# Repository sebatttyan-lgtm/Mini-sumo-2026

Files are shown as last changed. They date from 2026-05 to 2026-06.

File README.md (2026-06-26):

# MARK 38(mini sumo)

## DESCRIPCIÓN
El proyecto es un robot mini sumo diseñado por nosotros, con un tamaño y peso correspondiente a las [reglas de la LNR (Liga Nacional de Robótica)](https://sistema.lnr-argentina.com.ar/reglamentos/Sumo). este tiene la capacidad de detectar al contrincante para ir y atacar al otro mini sumo con el que este compitiendo para dejarlo fuera del dojo.

## ADMINISTRADORES DEL PROYECTO
1. **Thiago Lopez.** Diseño 3D y montaje de componentes en placa.
2. **Enzo Zapata.** Diseño de PCB, esquemático y montaje de componentes en placa. 
3. **Sebastián Pérez.** Programación, diseño esquemático y PCB y montaje de componentes en placa. 

## OBJETIVO
Nuestra meta con este proyecto es poder participar en la [LNR(Liga Nacional de Robótica)](https://lnr-argentina.com.ar/) y quedar en un puesto alto a la hora de terminar la competencia.Además, queremos lograr también la programación de mini sumo RC para poder competir entre amigos. 

## ESPECIFICACIONES TÉCNICAS
#### Tamaño del mini sumo: 10cm x 10cm x 8cm
#### Alimentación de operación: 11.1v 450mAh
#### Material empleado en la carrocería: PLA
#### Tipos de sensores empleados: Infrarrojo
#### Fuerza de torque:30Nm (Newton metros)

## COMPONENTES
### - SENSORES DE OBSTÁCULOS
#### [VL53L0X](https://components101.com/sensors/vl53l0x-lidar-distance-sensor) *(x5)*
### - SENSORES DE PISO
#### [QRE1113](https://www.alldatasheet.es/datasheet-pdf/view/54347/FAIRCHILD/QRE1113.html) *(x2)*
### - MOTORES
#### [MICROMOTORES N30 500rpm](https://www.aslongdcmotor.com/photo/aslongdcmotor/document/26865/JGA12-N30.pdf) *(x2)*
### - MICROCONTROLADOR 
#### [ESP32 C3 super mini](www.google.com/search?q=esp32+c3+super+mini&oq=esp32+c3+super+mini&gs_lcrp=EgZjaHJvbWUyBggAEEUYOdIBCDg1NzBqMGo3qAIAsAIA&sourceid=chrome&ie=UTF-8) *(x1)* 
### - DRIVER DE MOTOR (puente H)
#### [TA6586](https://www.alldatasheet.com/datasheet-pdf/pdf/1761575/RZ-MIC/TA6586.html) *(x2)*
### - BATERIA
#### [Tattu 3S 450mAh 11.1V 75C XT30](https://www.hobbymotors.com.ar/store/index.php?route=product/product&product_id=1127) *(x1)*
> (estos componentes son a grandes rasgos y no se han colocado todos los componentes, en el archivo "lista de componentes se encontrarán todos los materiales utilizados durante la produccion").

## DISEÑO DE LA PLACA

<div align="center">
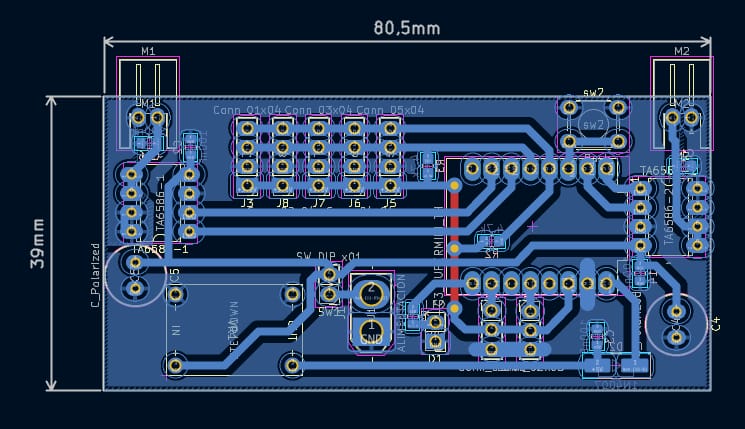
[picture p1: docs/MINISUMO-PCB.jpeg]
PCB Mini-sumo


## DISEÑO ESQUEMÁMITCO

<div align="center">
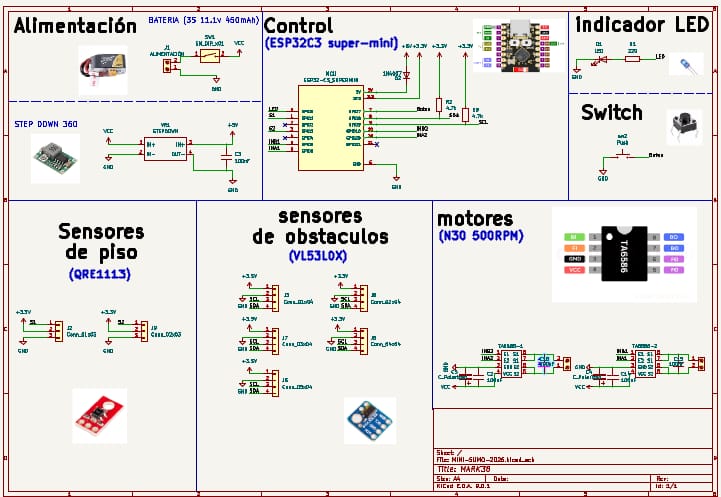
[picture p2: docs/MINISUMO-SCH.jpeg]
esquematico Mini-sumo


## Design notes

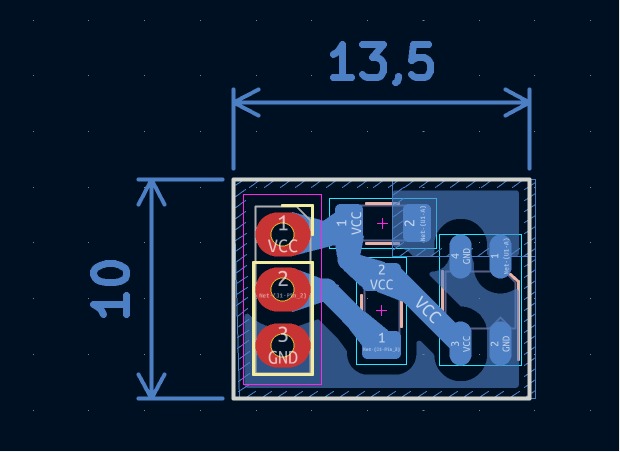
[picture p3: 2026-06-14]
docs/SENSORES-PCB.jpeg

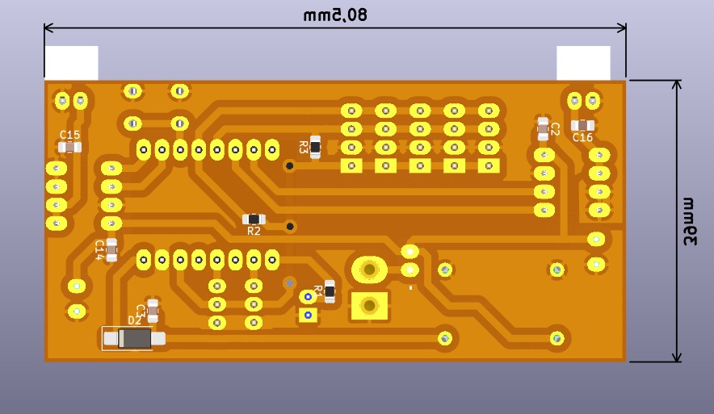
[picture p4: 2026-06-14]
docs/MINISUMO-3D-TRASERA.jpeg

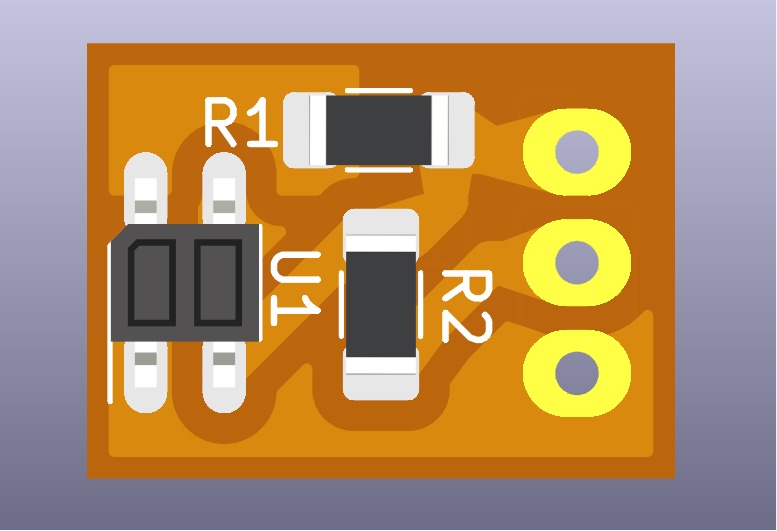
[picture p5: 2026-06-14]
docs/SENSORES-3D-TRASERA.jpeg

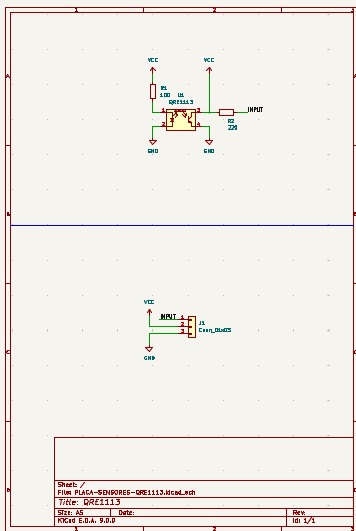
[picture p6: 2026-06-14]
docs/SENSORES-SCH.jpeg

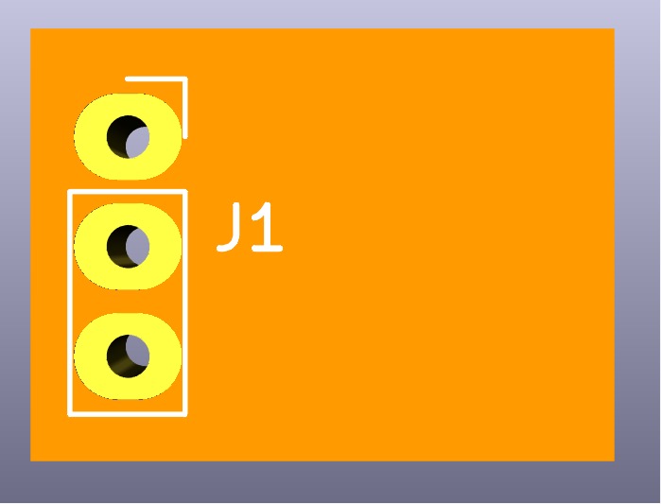
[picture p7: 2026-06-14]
docs/SENSORES-3D-FRONTAL.jpeg

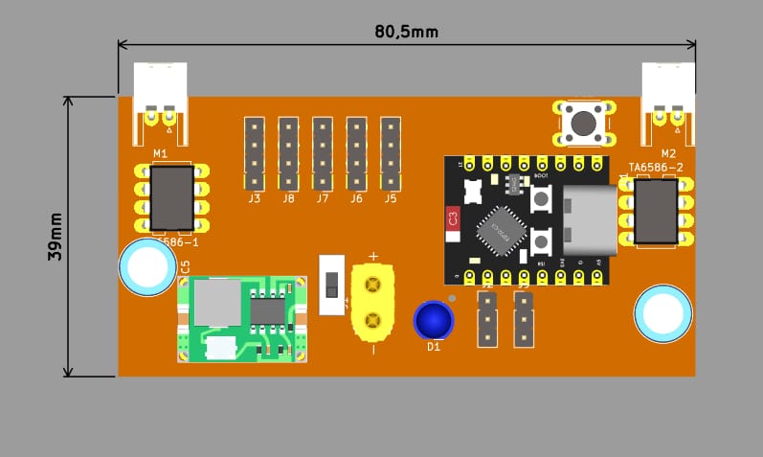
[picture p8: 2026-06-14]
docs/MINISUMO-3D-FRONTAL.jpeg

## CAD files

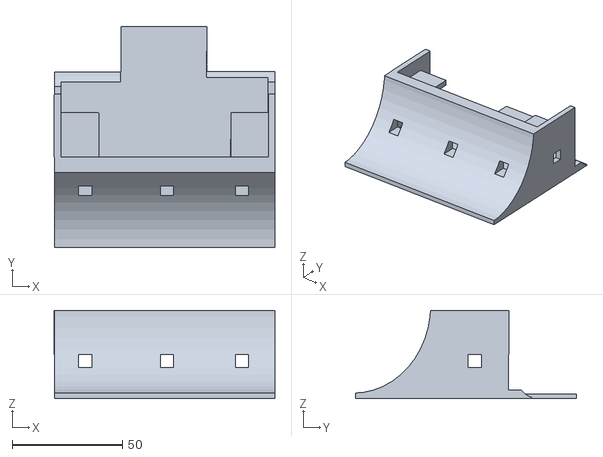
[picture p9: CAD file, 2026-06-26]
diseño 3D/MINI-SUMO.stl
100.2 x 100.0 x 40.0

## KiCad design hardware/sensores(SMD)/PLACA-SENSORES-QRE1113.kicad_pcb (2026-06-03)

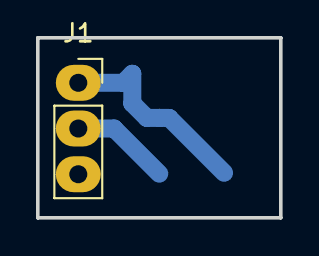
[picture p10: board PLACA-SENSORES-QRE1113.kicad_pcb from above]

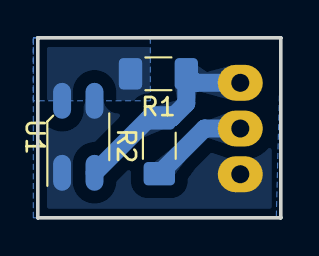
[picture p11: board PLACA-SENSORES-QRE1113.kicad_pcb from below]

Board: 2 copper layers, 13.5 x 10.0 mm, 4 parts (3 on the bottom side), 4 nets.

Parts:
J1: Conn_01x03; PinSocket_1x03_P2.54mm_Vertical
R1: 100; R_1206_3216Metric_Pad1.30x1.75mm_HandSolder
R2: 220; R_1206_3216Metric_Pad1.30x1.75mm_HandSolder
U1: QRE1113; OnSemi_CASE100AQ

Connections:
GND: J1.3, U1.2 (K), U1.4
unnamed: J1.2, R2.1
unnamed: R1.2, U1.1 (A)
VCC: J1.1, R1.1, R2.2, U1.3

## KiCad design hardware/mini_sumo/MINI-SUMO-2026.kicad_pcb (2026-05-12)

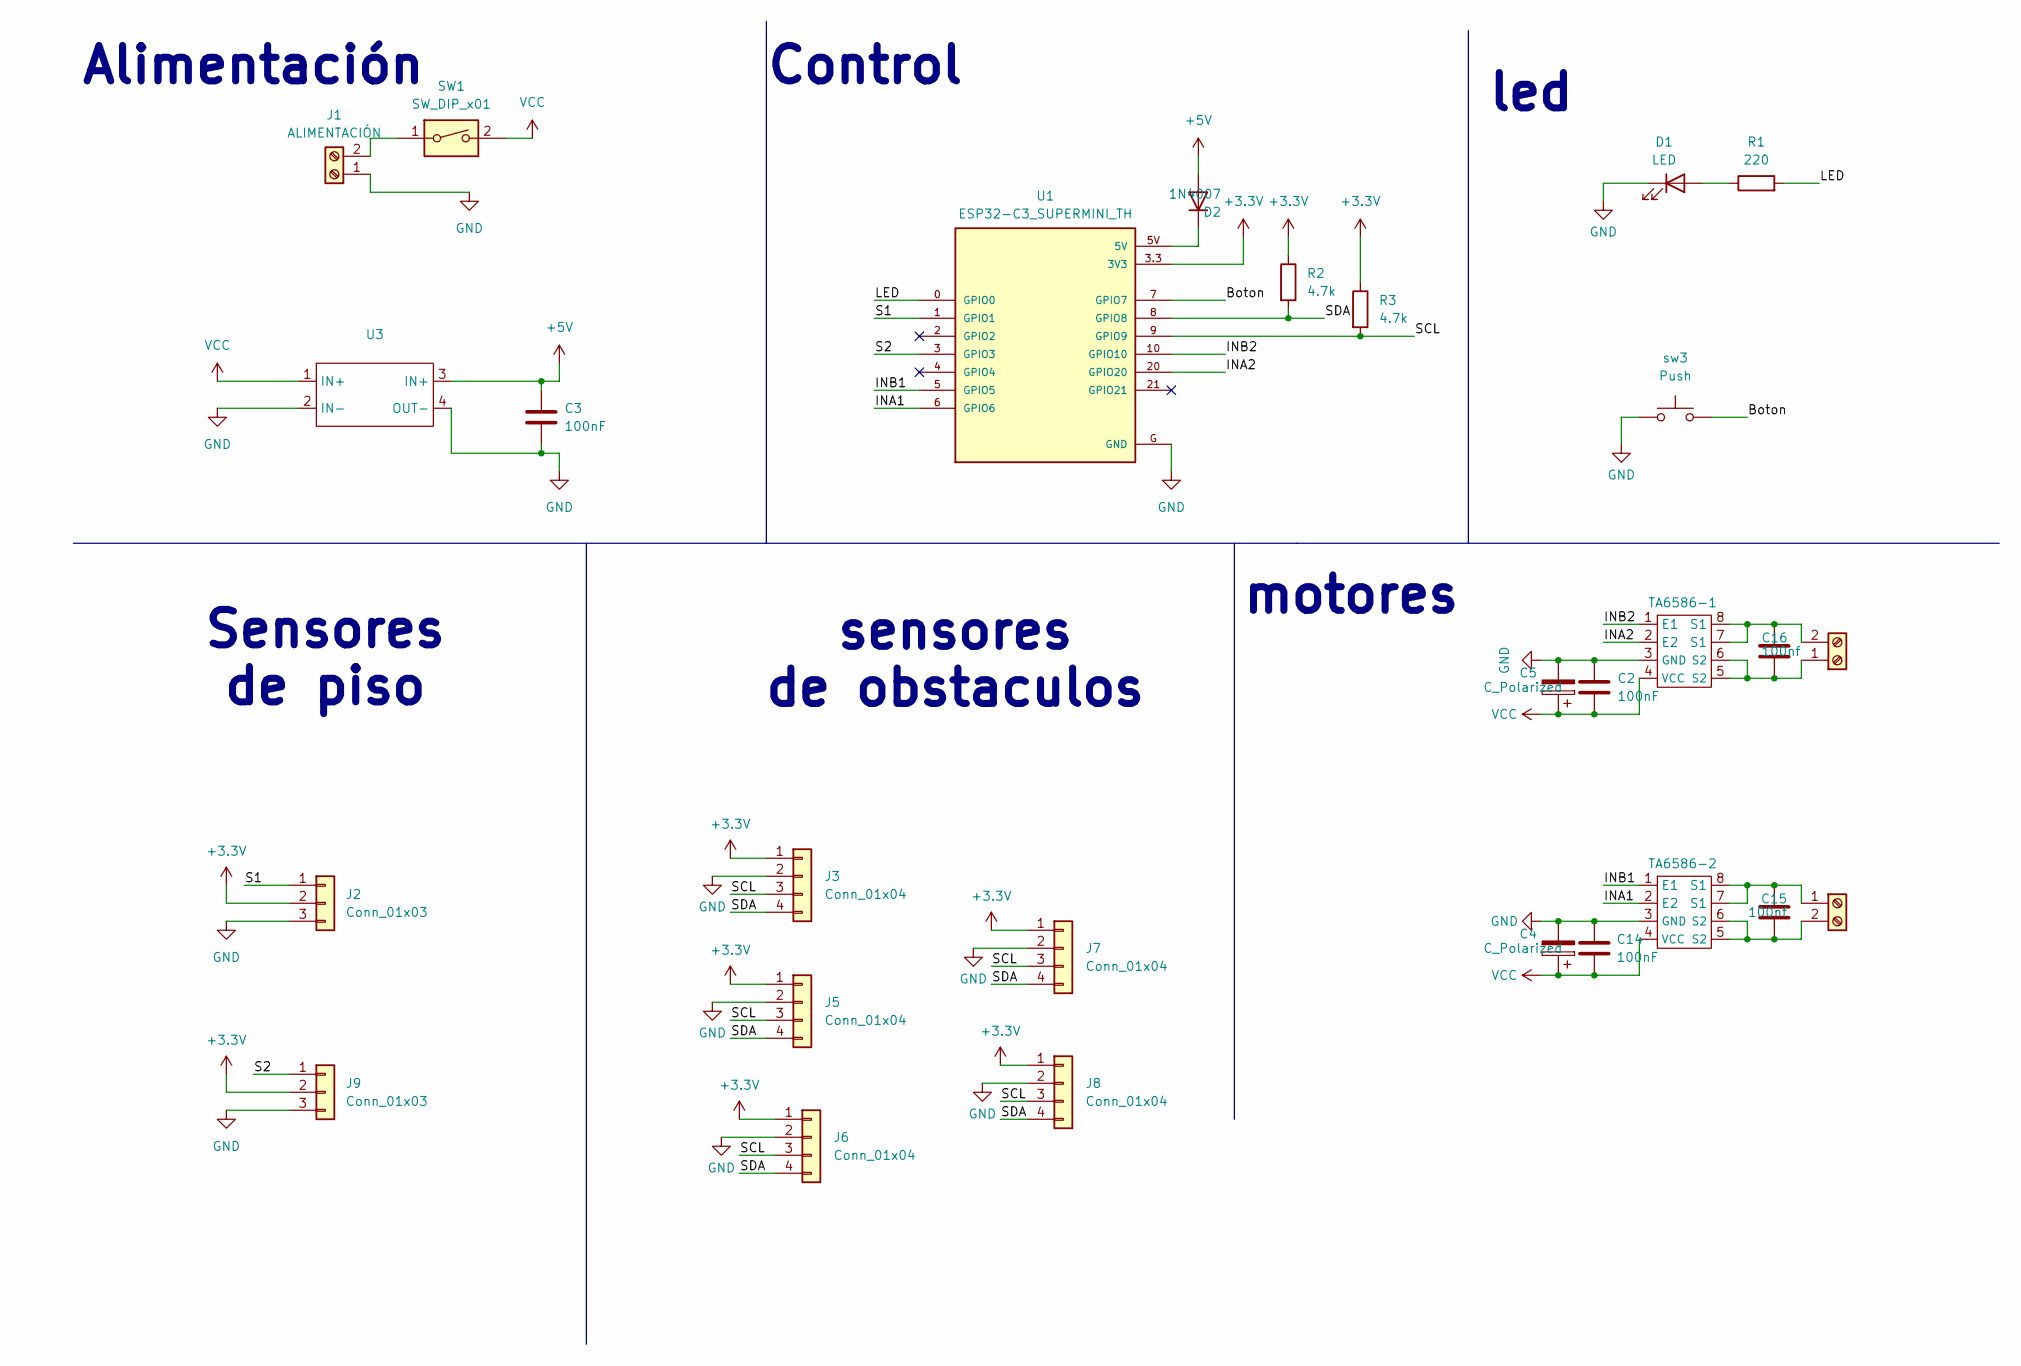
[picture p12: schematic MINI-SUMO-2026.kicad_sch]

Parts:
C2, C3, C14: 100nF; C_0805_2012Metric_Pad1.18x1.45mm_HandSolder
C4, C5: C_Polarized; C_Radial_D8.0mm_H11.5mm_P3.50mm
C15, C16: 100nf; C_0805_2012Metric_Pad1.18x1.45mm_HandSolder
D1: LED; PinHeader_1x02_P2.54mm_Vertical
D2: 1N4007; D_SMA_Handsoldering
J1: ALIMENTACIÓN; AMASS_XT30U-F_1x02_P5.0mm_Vertical
J2, J9: Conn_01x03; PinHeader_1x03_P2.54mm_Vertical
J3, J5, J6, J7, J8: Conn_01x04; PinHeader_1x04_P2.54mm_Vertical
M1: M1; JST_XH_S2B-XH-A-1_1x02_P2.50mm_Horizontal
M2: M2; JST_XH_S2B-XH-A-1_1x02_P2.50mm_Horizontal
R1: 220; R_0805_2012Metric_Pad1.20x1.40mm_HandSolder
R2, R3: 4.7k; R_0805_2012Metric_Pad1.20x1.40mm_HandSolder
SW1: SW_DIP_x01; PinHeader_1x02_P2.54mm_Vertical
TA6586-1, TA6586-2: DIP-8_W7.62mm
U1: ESP32-C3_SUPERMINI_TH; MODULE_ESP32-C3_SUPERMINI
U3: Mini360
sw3: Push; SW_PUSH_6mm_H4.3mm

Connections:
+3.3V: J2.2, J3.1, J5.1, J6.1, J7.1, J8.1, J9.2, R2.1, R3.1, U1.3.3 (3V3)
+5V: C3.1, D2.2 (A), U3.3 (IN+)
/Boton: U1.7 (GPIO7), sw3.2
/INA1: TA6586-2.2 (E2), U1.6 (GPIO6)
/INA2: TA6586-1.2 (E2), U1.20 (GPIO20)
/INB1: TA6586-2.1 (E1), U1.5 (GPIO5)
/INB2: TA6586-1.1 (E1), U1.10 (GPIO10)
/LED: R1.2, U1.0 (GPIO0)
/S1: J2.1, U1.1 (GPIO1)
/S2: J9.1, U1.3 (GPIO3)
/SCL: J3.3, J5.3, J6.3, J7.3, J8.3, R3.2, U1.9 (GPIO9)
/SDA: J3.4, J5.4, J6.4, J7.4, J8.4, R2.2, U1.8 (GPIO8)
GND: C2.1, C3.2, C4.2, C5.2, C14.1, D1.1 (K), J1.1, J2.3, J3.2, J5.2, J6.2, J7.2, J8.2, J9.3, TA6586-1.3 (GND), TA6586-2.3 (GND), U1.G (GND), U3.2 (IN-), U3.4 (OUT-), sw3.1
unnamed: D1.2 (A), R1.1
unnamed: D2.1 (K), U1.5V
unnamed: J1.2, SW1.1
unnamed: C16.2, M1.1, TA6586-1.5 (S2), TA6586-1.6 (S2)
unnamed: C16.1, M1.2, TA6586-1.7 (S1), TA6586-1.8 (S1)
unnamed: C15.1, M2.1, TA6586-2.7 (S1), TA6586-2.8 (S1)
unnamed: C15.2, M2.2, TA6586-2.5 (S2), TA6586-2.6 (S2)
VCC: C2.2, C4.1, C5.1, C14.2, SW1.2, TA6586-1.4 (VCC), TA6586-2.4 (VCC), U3.1 (IN+)

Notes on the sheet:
Control
motores
sensores de obstaculos
Sensores de piso
led
Alimentación

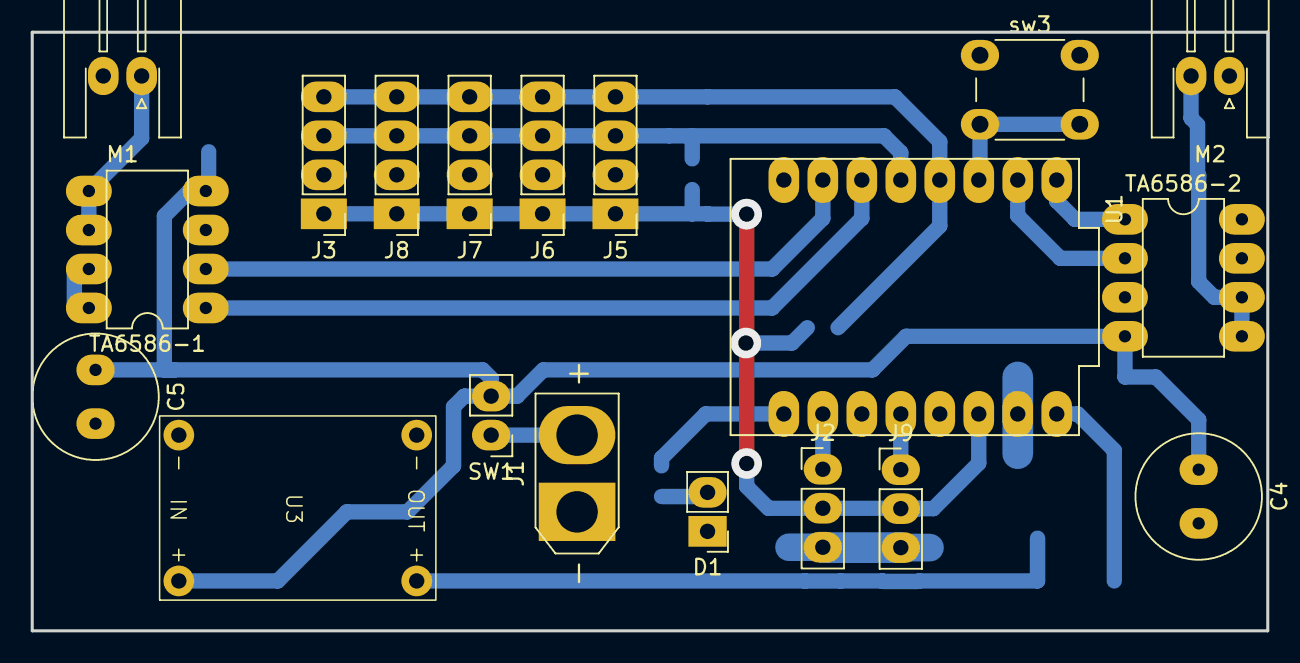
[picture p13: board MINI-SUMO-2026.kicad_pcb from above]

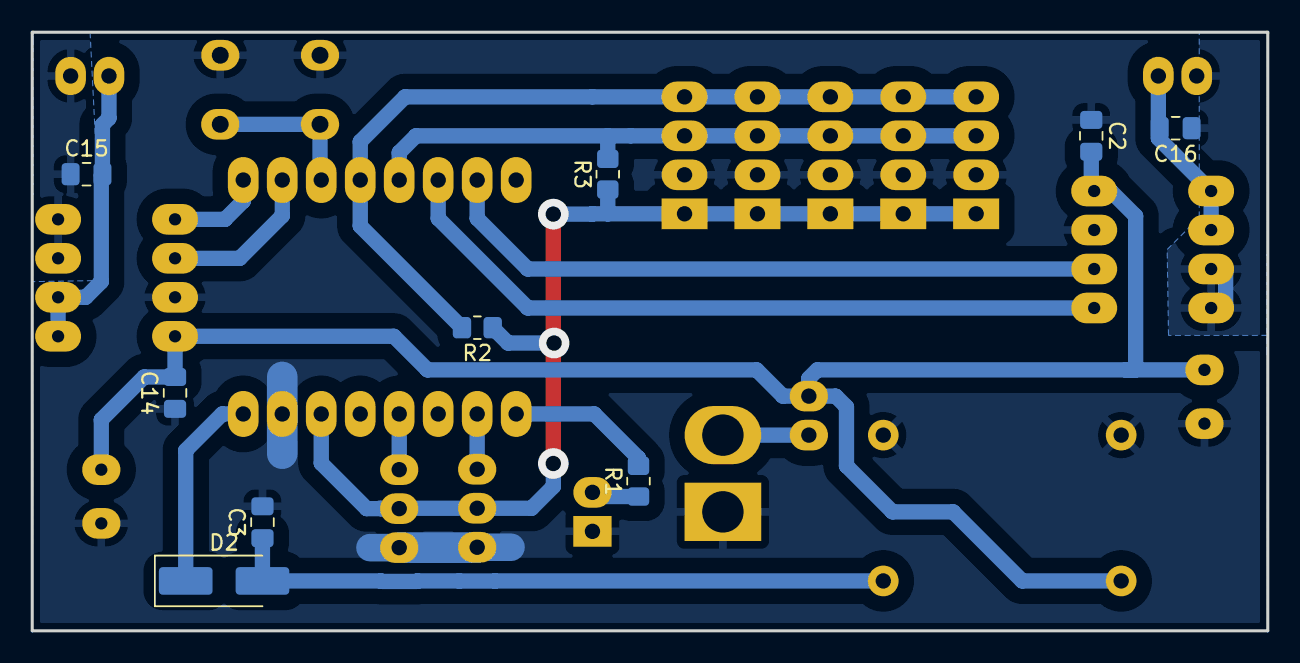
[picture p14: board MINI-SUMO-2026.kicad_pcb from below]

Board: 2 copper layers, 80.5 x 39.0 mm, 28 parts (9 on the bottom side), 21 nets.

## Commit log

2026-05-27 Update README.md
    Primera actualización del readme, aun falta agregar imagenes de pcb, 3d, esquemático
2026-06-03 añadi pcb de sensores en SMD
    [PLACA-SENSORES-QRE1113.kicad_pcb, PLACA-SENSORES-QRE1113.kicad_sch]
2026-06-03 Create carpeta-sensores(th)
2026-06-14 Update README.md
    actualización del readme (incluye especificaciones tecnicas y el link de la primera descripción)
2026-06-14 Update carpeta-sensores(th)
2026-06-14 add images to docs
    incluir fotos del pcb, 3d y esquemático del mini sumo y plaqueta de los sensores
2026-06-14 Rename WhatsApp Image 2026-06-14 at 00.52.17.jpeg to MINISUMO-PCB.jpeg
2026-06-14 Rename WhatsApp Image 2026-06-14 at 00.59.34.jpeg to SENSORES-PCB.jpeg
2026-06-14 Rename WhatsApp Image 2026-06-14 at 01.03.38.jpeg to SENSORES-SCH.jpeg
2026-06-14 Rename WhatsApp Image 2026-06-14 at 01.04.18.jpeg to SENSORES-3D-FRONTAL.jpeg
2026-06-14 Rename WhatsApp Image 2026-06-14 at 01.04.47.jpeg to SENSORES-3D-TRASERA.jpeg
